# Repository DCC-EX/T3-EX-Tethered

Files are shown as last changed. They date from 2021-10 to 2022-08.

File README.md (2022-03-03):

# T3-Ex-Tethered
### Arduino based throttle for DCC++Ex

#### ⚠ This is Beta code and may have unknown bugs, please report any issues on GitHub ⚠

#### It uses off the shelf parts but will require a degree Tinkerer knowledge to build your own. This document contains my own wiring methods, I'm not liable for any damage you cause from incorrect wiring.

## Parts
 - Arduino Mega
 - [Adafruit 2.8" TFT Touch Shield - Capacitive](https://learn.adafruit.com/adafruit-2-8-tft-touch-shield-v2)
 - Rotary Encoder Board KY-040
 - Jumper wire
 - 4 core cable
 - 8GB microSD card (not required but needed for custom loco configs)

**\*NOTES\***
I've tried to keep it as simple as possible but it will require some 3D printed parts (STEP & STL included).
Not all KY-040 boards are created equal so it's best to check dimensions before doing any printing.

## Wiring
The KY-040 encoder needs to be wired as follows
|KY-040|Mega|
|--|--|
|GND|GND|
|+|5v|
|SW|A12|
|DT|18|
|CLK|19|

### Power
The throttle can be powered via the 5v pin with a regulated 5v supply or if your CS only has a motor shield you can get 5v from that. Remember to connect a ground to the CS from the throttle.
**\*WARNING\***
Don't connect the throttle via USB at the same time as being powered by the 5v pin.

### Connecting to the CS
The throttle uses `Serial2` (Pins 16 & 17), you'll need to connect these to a Serial port on the CS (If the CS is a Mega there's 3 to choose from).
Make sure you connect the GND's of both the throttle and CS together too.

**Command Station v4**
CS v4 made it much simpler to add an extra `Serial` input.
You just need to add which serial to use to your `config.h` file, e.g.
`#define SERIAL1_COMMANDS`

**Command Station v3.1**
The CS sketch will need a couple lines of extra code to handle the throttle.
Just before `void setup()` you'll need to create a new parser object, `DCCEXParser serialParser2;`.
In `void setup()` you'll need to start the serial port you decide to use, e.g. `Serial1.begin(115200);` then in `void loop()` you'll need to tell the serial parser to handle the serial, e.g. `serialParser2.loop(Serial1);`

## SD card structure
```
.
├── locos
│   ├── 1.json
│   └── 2.json
├── icons
│   ├── lights-on.bmp
│   └── lights-off.bmp
├── fns
│   ├── hornby.json
│   └── dcc-concepts.json
└── groups.json
```

## Loco config
The JSON file name is the loco address, e.g. `1234.json` has the name and function mapping for a loco on address #1234.

```js
{
  /* loco name/description, max 20 characters */
  "name": "00000000000000000000",
  /* decoder functions */
  "functions": [
    /* function buttons are in rows, a new array starts a new row. max 4 buttons per row. */
    [
      {
        /* function # */
        "fn": 0,
        /* Optional: button label, max 20 characters, *NOTE* 20 is the max but if you have multiple buttons on a row the text may overflow */
        "label": "Lights",
        /* Optional: is the button latching? default is true */
        "latching": true,
        /* Optional: button styles, if not specified it defaults to black and white */
        "btn": {
          /* idle button style */
          "idle": {
            /* fill colour, RGB */
            "fill": 1,
            /* text colour, RGB */
            "text": 1,
            /* icon file name, needs to be in the icons directory, the bmp file extension isn't needed as all icons need to be bmp images */
            "icon": "lights-off"
          },
          /* pressed button style */
          "pressed": {
            /* fill colour, RGB */
            "fill": 1,
            /* text colour, RGB */
            "text": 1,
            /* icon file name, needs to be in the icons directory, the bmp file extension isn't needed as all icons need to be bmp images */
            "icon": "lights-on"
          }
        }
      },
      {
        "fn": 2,
        "label": "Horn",
        "latching": false
      }
    ]
  ]
}
```
You can create a reusable function map file for specific decoders to save duplicating, e.g. `dcc-concepts.json`.
This needs to be in the `fns` directory and its name used as the value for the `functions` key, e.g. `"functions":"dcc-concepts"`.

These configs only need the rows and function declarations.
e.g.
```js
[
  [
    {
      "name": "Function 1",
      "fn": 1,
      // ...
    },
    {
      "name": "Function 2",
      "fn": 2,
      // ...
    }
  ]
]
```

## Icons
Icons need to be 24bit bmp images with max dimensions of 30x30.
As bmp's don't have opacity you'll need to set the background to the same colour you use for the fill.

## General functionality
A loco can be acquired by using the `By Address`, `By Name` or `Favs` buttons.

**By Address** will display a keypad where the loco address can be entered.
**By Name** will list detected loco names from the json configs. Touching a name button will acquire the loco (*\*The order is unspecified and may change with any changes to the SD card\**).
**Groups** allows you to create named loco groups which will list loco names in the order specified by the `groups.json` config. The `groups.json` file should contain a JSON object where the key is the group name and the value should be an array of loco addresses, e.g.
```json
{
  "Group Name": [1,2,3,4],
  "Class 66": [5,6,7,8]
}
```

**Release** will release the currently acquired loco.

**Program**, this allows for reading and writing CV's. A keypad will be displayed to allow entering numeric CV values.

**Menu Icon**, touching this icon will show the menu, if a loco has been acquired touching again will take you back to the loco display so you don't need to reselect it.

**Rotary Encoder**, clockwise rotation will increase the current loco speed and anti-clockwise rotation will decrease the loco speed.
A press of the rotary encoder will change the current loco direction.

**Emergency Stop**, press and hold the rotary encoder for 2+ seconds and all active locos will stop.

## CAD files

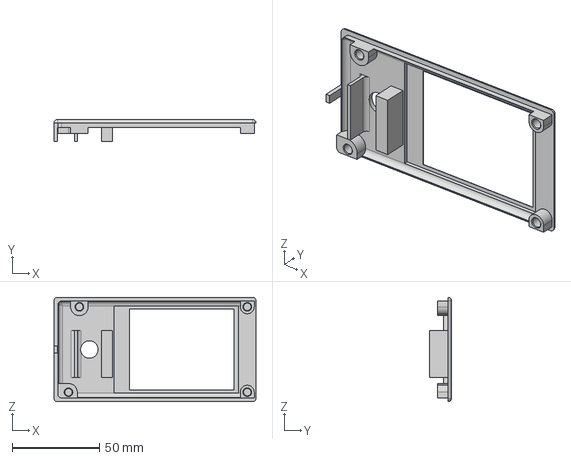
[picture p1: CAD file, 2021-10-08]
3d/Top.step
116.0 x 12.7 x 60.0 mm

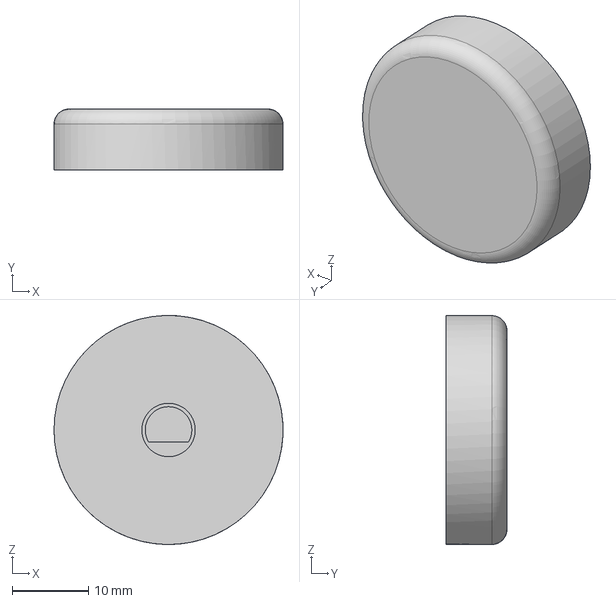
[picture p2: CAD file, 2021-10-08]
3d/Dial.step
30.0 x 8.00 x 30.0 mm

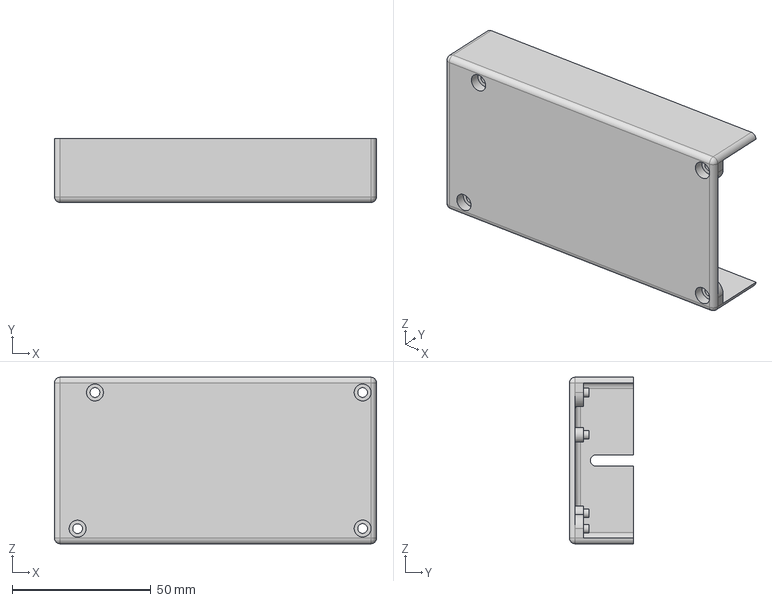
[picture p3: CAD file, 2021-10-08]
3d/Base.step
116.0 x 23.1 x 60.0 mm

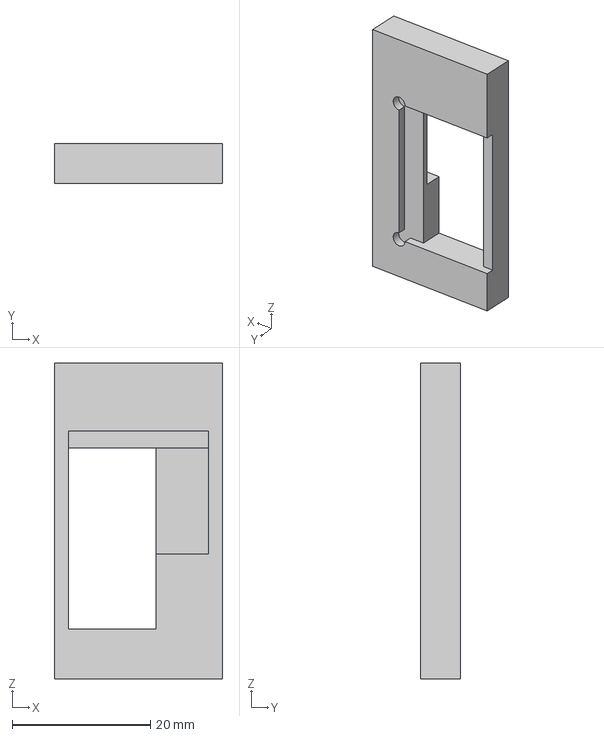
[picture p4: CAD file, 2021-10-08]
3d/Encoder Mount.step
24.3 x 5.75 x 45.7 mm

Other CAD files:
3d/Base.stl
3d/Dial.stl
3d/Encoder Mount.stl
3d/Top.stl

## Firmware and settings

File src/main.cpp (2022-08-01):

#include <Arduino.h>
#include <EEPROM.h>
#include <SdFat.h>
#include <Adafruit_ILI9341.h>
#include <Adafruit_FT6206.h>
#include <Fonts/FreeSans9pt7b.h>
#include <Encoder.h>
#include <ArduinoJson.h>

#include <TouchRegion.h>
#include <TouchButton.h>
#include <DCCEx.h>
#include <UI.h>
#include <Menu.h>
#include <LocoByAddress.h>
#include <LocoByName.h>
#include <Loco.h>
#include <Program.h>

// #define THROTTLE_DEBUG

// Pins
const uint8_t TFT_CS = 10;
const uint8_t TFT_DC = 9;
const uint8_t SD_CS = 4;

const uint8_t ENCODER_A = 18;
const uint8_t ENCODER_B = 19;
const uint8_t ENCODER_BTN = A12;

SdFat sd; // SD FileSystem
Adafruit_ILI9341 tft = Adafruit_ILI9341(TFT_CS, TFT_DC); // TFT
Adafruit_FT6206 ts = Adafruit_FT6206(); // Touch Screen
TS_Point tp;

Encoder encoder(ENCODER_A, ENCODER_B); // Encoder
struct EncoderButtonStateEnum {
  enum State : uint8_t {
    IDLE,
    PRESSED,
    RELEASED
  };
};
typedef EncoderButtonStateEnum::State EncoderButtonState;
uint32_t encoderPressMillis = 0;
uint8_t encoderBtnState = EncoderButtonState::IDLE;
uint8_t currentEncoderPinState, lastEncoderPinState;

const uint8_t MAX_LOCOS = 50;
LocoState locos[MAX_LOCOS]; // Max 50, same as DCC++Ex
DCCEx dcc(&Serial2); // DCC++Ex Interface

bool rotated = false;
TouchRegion menu(208, 0, 32, 22); // Menu
UI *activeUI = nullptr;
int8_t activeLoco = -1;
bool isMenuUI = false;
void clearAndDrawMenuUI();
void setMenuUI();

#ifdef THROTTLE_DEBUG
// https://learn.adafruit.com/memories-of-an-arduino/measuring-free-memory#sram-370031-5
#ifdef __arm__
// should use uinstd.h to define sbrk but Due causes a conflict
extern "C" char* sbrk(int incr);
#else  // __ARM__
extern char *__brkval;
#endif  // __arm__

int freeMemory() {
  char top;
#ifdef __arm__
  return &top - reinterpret_cast<char*>(sbrk(0));
#elif defined(CORE_TEENSY) || (ARDUINO > 103 && ARDUINO != 151)
  return &top - __brkval;
#else  // __arm__
  return __brkval ? &top - __brkval : &top - __malloc_heap_start;
#endif  // __arm__
}
#endif

/**
 * @brief Get the index of the LocoState object
 * If the address isn't found in the `locos` array it'll add it to the first empty one
 * 
 * @param address 
 * @return int8_t 
 */
int8_t getLoco(uint16_t address) {
  int8_t firstEmpty = -1;
  for (uint8_t i = 0; i < MAX_LOCOS; i++) {
    if (firstEmpty == -1 && locos[i].address == 0) {
      firstEmpty = i;
    } else if (locos[i].address == address) {
      return i;
    }
  }

  if (firstEmpty != -1) {
    locos[firstEmpty].address = address;
  }
  return firstEmpty;
}

/**
 * @brief Free the `LocoState` for the address specified
 * 
 * @param address 
 */
void freeLoco(uint16_t address) {
  for (uint8_t i = 0; i < MAX_LOCOS; i++) {
    if (locos[i].address == address) {
      locos[i] = LocoState();
      return;
    }
  }
}

/**
 * @brief Draw the menu burger icon
 */
void drawMenuIcon() {
  tft.fillRect(208, 0, 32, 4, ILI9341_WHITE);
  tft.fillRect(208, 9, 32, 4, ILI9341_WHITE);
  tft.fillRect(208, 18, 32, 4, ILI9341_WHITE);
}

/**
 * @brief Change the current UI. This will clear the screen, free the current `UI` then set the new active
 * 
 * @tparam T 
 * @param ui 
 */
template<typename T>
void setUI(T&& ui) {
  tft.fillRect(0, 0, 207, 22, ILI9341_BLACK);
  tft.fillRect(0, 22, 240, 298, ILI9341_BLACK);

  delete activeUI;
  activeUI = ui();
}

/**
 * @brief Set the active UI to `Loco`
 */
void setLocoUI() {
  setUI([]() {
    return new Loco(&tft, &sd, &dcc, &locos[activeLoco]);
  });
}

/**
 * @brief Set the active UI to `LocoByAddress`
 * If an address is provided it'll be set as the active loco
 * If the KeyPad is cancelled we go back to the menu UI
 */
void setLocoByAddressUI() {
  setUI([]() {
    return new LocoByAddress(&tft, [](uint16_t value) { // Loco selected callback
      if (value != 0) {
        activeLoco = getLoco(value);
        setLocoUI();
      } else {
        setMenuUI();
      }
    });
  });
}

/**
 * @brief Set the active UI to `LocoByName`
 * If an address is provided it'll be set as the active loco
 */
void setLocoByNameUI(bool groups) {
  setUI([groups]() {
    return new LocoByName(&tft, &sd, groups, [](uint16_t value) { // Loco selected callback
      if (value != 0) {
        activeLoco = getLoco(value);
      }
      setLocoUI();
    });
  });
}

/**
 * @brief Set the active UI as `Program`
 */
void setProgramUI() {
  setUI([]() {
    return new Program(&tft, &dcc);
  });
}

/**
 * @brief Set the active UI as `Menu`
 * The `Menu` UI has a callback for when a menu button is pressed
 */
void setMenuUI() {
  isMenuUI = true;
  setUI([]() {
    return new Menu(&tft, [](uint8_t btn) { // Menu option callback
      switch (btn) {
        case MenuButton::ROTATE: {
          rotated = !rotated;
          tft.setRotation(rotated ? 2 : 0);

          EEPROM.update(0, !rotated);
          
          clearAndDrawMenuUI();
        } break;
        case MenuButton::LOCO_LOAD_BY_ADDRESS: {
          isMenuUI = false; 
          setLocoByAddressUI();
        } break;
        case MenuButton::LOCO_LOAD_BY_NAME:
        case MenuButton::LOCO_LOAD_BY_GROUP: {
          isMenuUI = false; 
          setLocoByNameUI(btn == MenuButton::LOCO_LOAD_BY_GROUP);
        } break;
        case MenuButton::LOCO_RELEASE: {
          dcc.release(locos[activeLoco].address);
          locos[activeLoco] = { };
          activeLoco = -1;
        } break;
        case MenuButton::LOCO_PROGRAM: {
          isMenuUI = false; 
          setProgramUI();
        } break;
        case MenuButton::POWER_OFF_ALL: {
          dcc.powerOff(Track::ALL);
        } break;
        case MenuButton::POWER_ON_ALL: {
          dcc.powerOn(Track::ALL);
        } break;
        case MenuButton::POWER_OFF_MAIN: {
          dcc.powerOff(Track::MAIN);
        } break;
        case MenuButton::POWER_ON_MAIN: {
          dcc.powerOn(Track::MAIN);
        } break;
        case MenuButton::POWER_OFF_PROG: {
          dcc.powerOff(Track::PROG);
        } break;
        case MenuButton::POWER_ON_PROG: {
          dcc.powerOn(Track::PROG);
        } break;
        case MenuButton::POWER_JOIN: {
          dcc.powerJoin();
        } break;
      };
    });
  });
}

/**
 * @brief Clear the screen and redraw the menu icon and menu UI
 */
void clearAndDrawMenuUI() {
  // Clear screen
  tft.fillScreen(ILI9341_BLACK);
  // Menu burger icon
  drawMenuIcon();
  // Start with the menu
  setMenuUI();
}

void setup() {
  #ifdef THROTTLE_DEBUG
  Serial.begin(115200);
  #endif

  // Setup interrupt for the encoder button
  pinMode(ENCODER_BTN, INPUT_PULLUP);

  if (!sd.begin(SD_CS)) {
    // TODO, print error to tft?
  }

  // Setup the screen
  tft.begin();
  tft.setFont(&FreeSans9pt7b);
  ts.begin();

  // Should we rotate?
  rotated = !EEPROM.read(0);
  if (rotated) {
    tft.setRotation(2);
  }

  clearAndDrawMenuUI();
}

void loop() {
  // Encoder press
  currentEncoderPinState = digitalRead(ENCODER_BTN);
  if (currentEncoderPinState != lastEncoderPinState) {
    if (millis() - encoderPressMillis > 50) { // Debounce
      if (currentEncoderPinState == LOW && encoderBtnState == EncoderButtonState::IDLE) { // Press
        encoderBtnState = EncoderButtonState::PRESSED;
      } else if (currentEncoderPinState == HIGH && encoderBtnState == EncoderButtonState::PRESSED) { // Release
        encoderBtnState = EncoderButtonState::RELEASED;
      }
    }
    encoderPressMillis = millis();
  }
  lastEncoderPinState = currentEncoderPinState;

  if (ts.touched()) {
    #ifdef THROTTLE_DEBUG
    Serial.println(freeMemory());
    #endif
    // Remap the touch point
    tp = ts.getPoint(); 
    tp.x = map(tp.x, 0, 240, 240, 0);
    tp.y = map(tp.y, 0, 320, 320, 0);

    if (rotated) { // Invert touch points if rotated
      tp.x = 240 - tp.x;
      tp.y = 320 - tp.y;
    }

    if (menu.contains(tp)) { // Menu press?
      while (ts.touched()) {
        delay(50);
      }
      if (isMenuUI) { // If the menu is the current UI and we have an active loco we switch to the `Loco` UI
        if (activeLoco != -1) {
          isMenuUI = false;
          setLocoUI();
        }
      } else { // If current UI isn't `Menu` then switch to that
        setMenuUI();
      }
    } else { // Send the touch to the active UI
      activeUI->touch(tp.x, tp.y, []() { return ts.touched(); });
    }
  } else if (encoder.read() != 0) { // Encoder change, send to active UI
    int32_t read = encoder.read();
    if (read >= 2) {
      activeUI->encoderChange(CW);
      encoder.write(0);
    } else if (read <= -2) {
      activeUI->encoderChange(CCW);
      encoder.write(0);
    }
  } else if (encoderBtnState == EncoderButtonState::PRESSED && millis() - encoderPressMillis > 2000) { // Encoder pressed and held for more than 2 seconds
    encoderBtnState = EncoderButtonState::IDLE;
    dcc.emergencyStopAll(); // Stop all locos
    for (uint8_t i = 0; i < MAX_LOCOS; i++) { // Reset all loco speeds to zero
      locos[i].speed = 0;
    }
    activeUI->encoderPress(true);
  } else if (encoderBtnState == EncoderButtonState::RELEASED && millis() - encoderPressMillis < 1000) { // Encoder pressed for less than 1 second
    encoderBtnState = EncoderButtonState::IDLE;
    activeUI->encoderPress();
  }
  dcc.clearCSResponse();
}
